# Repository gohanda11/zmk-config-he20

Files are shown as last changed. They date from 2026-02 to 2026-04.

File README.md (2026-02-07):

# HE20 - Hall Effect キーボード

XIAO nRF52840 + SN74LV4051A x3 + GH39FKSW による Hall Effect キーボードの ZMK ファームウェア設定。

## ハードウェア構成

| 要素 | 仕様 |
|---|---|
| MCU | Seeed XIAO nRF52840 |
| Hall Effect スイッチ | GH39FKSW |
| アナログマルチプレクサ | SN74LV4051A x 3 |
| トラックボールセンサー | PMW3610 ([zmk-pmw3610-driver](https://github.com/gohanda11/zmk-pmw3610-driver)) |
| ドライバ | [zmk-feature-hall-effect](https://github.com/gohanda11/zmk-feature-hall-effect) (フォーク版) |

## キーレイアウト

22 スイッチ位置を全て定義。未実装のキーは `&none` を割り当てる。

```
┌──────┬──────┬──────┬──────┬──────┐
│ HE1  │ HE2  │ HE3  │ HE4  │ HE5  │  Row 0
├──────┼──────┼──────┼──────┼──────┤
│ HE6  │ HE7  │ HE8  │ HE9  │ HE10 │  Row 1
├──────┼──────┼──────┼──────┼──────┤
│ HE11 │ HE12 │ HE13 │ HE14 │ HE15 │  Row 2
├──────┼──────┼──────┼──────┼──────┤
│ HE16 │ HE17 │ HE18 │ HE19 │ HE20 │  Row 3
└──────┴──────┴──────┴──────┴──────┘
┌─────────────┐      ┌─────────────┐
│  HE21 (2U)  │      │  HE22 (2U)  │  Row 4
└─────────────┘      └─────────────┘
```

Row 3 の 1U キーと Row 4 の 2U キーは物理的に入れ替えて使用できる。
取り付けていないキーには `&none` を設定する。

## トラックボール

PMW3610 センサーを J1 コネクタ経由で接続。

| 信号 | ピン | GPIO |
|---|---|---|
| CS | D0 | P0.02 |
| SDIO (MOSI/MISO) | D4 | P0.04 |
| SCLK | D5 | P0.05 |
| MOTION (IRQ) | D6 | P1.11 |

- automouse-layer: MOUSE (layer 1) - トラックボール操作時に自動切替
- scroll-layers: SCROLL (layer 5) - スクロールモード

## ビルド方法

GitHub Actions で自動ビルド。push すると `.github/workflows/build.yml` が実行される。

## ファイル構成

```
zmk-config-he20/
├── .github/workflows/build.yml
├── build.yaml
├── zephyr/module.yml
├── config/
│   ├── west.yml              # ZMK + zmk-feature-hall-effect モジュール定義
│   ├── he20.keymap            # キーマップ (7レイヤー)
│   └── he20.json              # 物理レイアウト定義 (keymap-editor 用)
└── boards/shields/he20/
    ├── Kconfig.shield
    ├── Kconfig.defconfig
    ├── he20.conf              # Kconfig 設定
    ├── he20.overlay           # Devicetree (kscan, レイアウト, transform)
    └── he20.zmk.yml           # シールドメタデータ
```

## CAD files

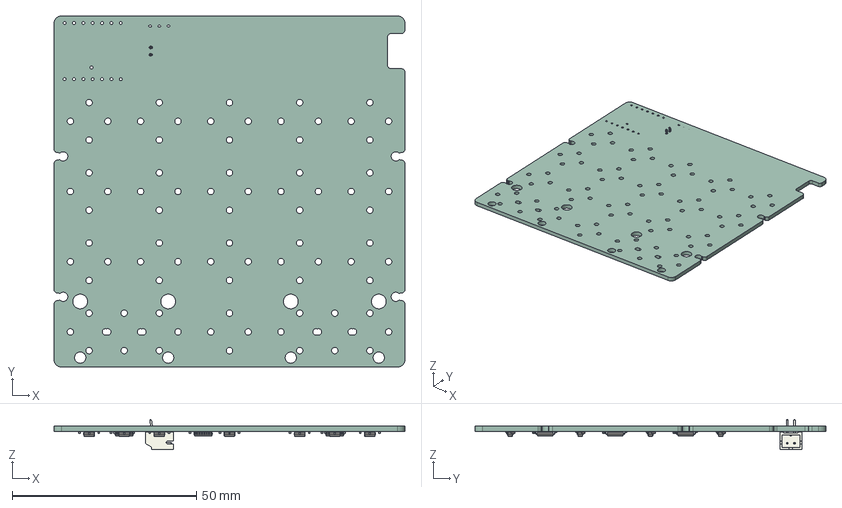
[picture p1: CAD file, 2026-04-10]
data/pcb.step
95.2 x 95.2 x 8.25 mm
SOT-23-3 x 22
C_0402_1005Metric x 47
TSSOP-16_4.4x5mm_P0.65mm x 3
JST_PH_S2B-PH-K_1x02_P2.00mm_Horizontal
xiao-test_PCB

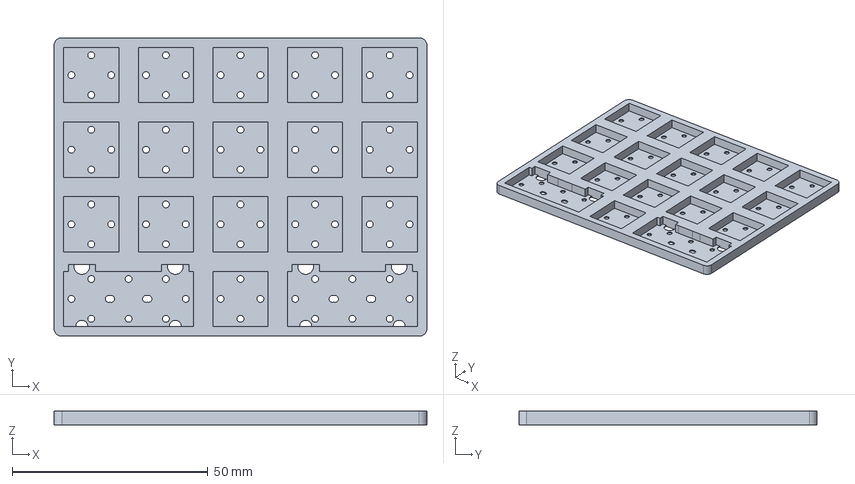
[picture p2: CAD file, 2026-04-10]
data/form.stp
95.2 x 76.2 x 3.50 mm

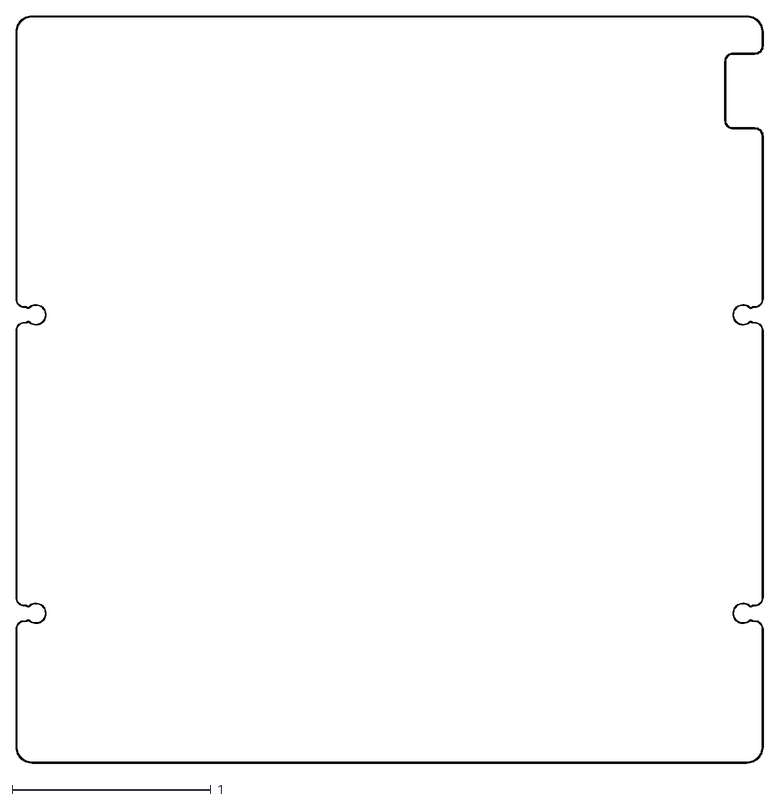
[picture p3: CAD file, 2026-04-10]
data/he20-Edge_Cuts.dxf
3.75 x 3.75

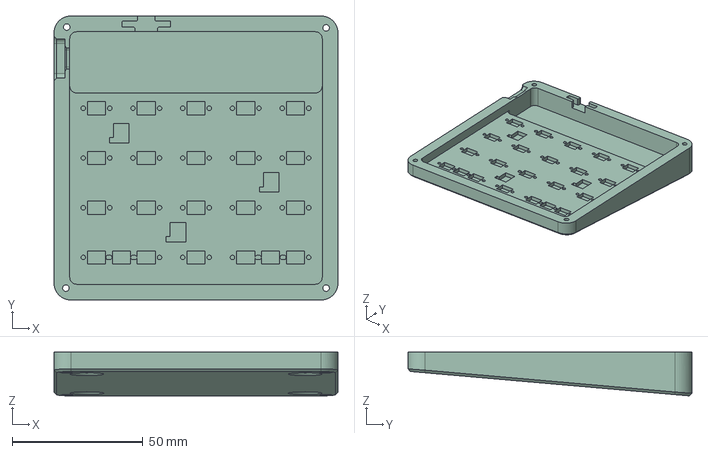
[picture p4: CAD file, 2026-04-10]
data/case_bottom.stp
108.8 x 108.8 x 16.8 mm

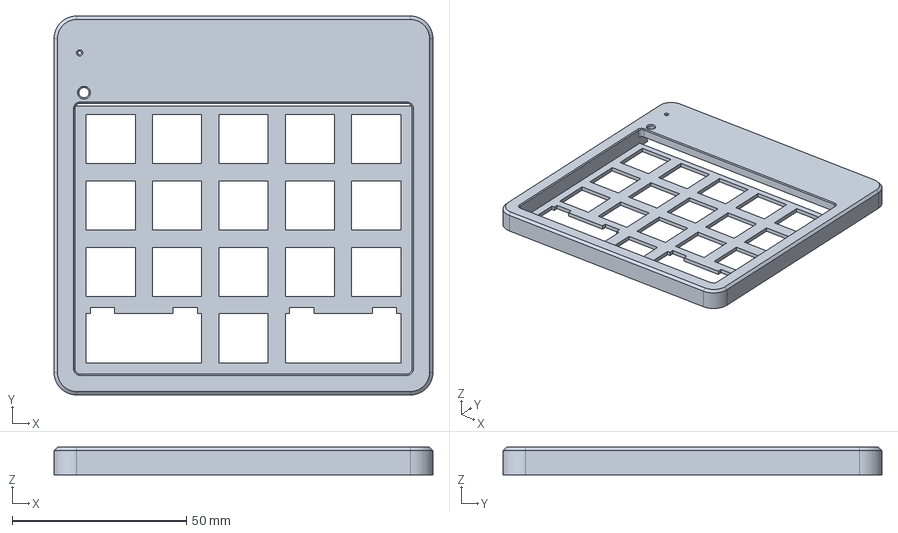
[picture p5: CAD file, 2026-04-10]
data/case_top.stp
108.8 x 108.8 x 8.00 mm

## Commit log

2026-02-07 fix: update board name for Zephyr 4.1.0 compatibility
    Rename seeeduino_xiao_ble to xiao_ble to match the new board naming
    convention in Zephyr 4.1.0.
2026-02-07 fix: move &he_pass node reference outside root block
    Node reference overrides (&label { }) must be at the top level of the
    devicetree file, not inside the / { } block.
2026-02-07 feat: switch to GH39FKSW sensor and default to 2U right layout
    - Change default physical layout from 1U to transform_2u_right (19 keys)
    - Update keymap to 19-key layout (Row 3: HE16, HE17, HE18, HE22)
    - Update sensor reference from MT9102ET to GH39FKSW
    - Update he20.zmk.yml requires to xiao_ble
    - Rewrite README with updated hardware info and layout docs
2026-02-07 refactor: use single 22-key layout showing all switch positions
    Replace the 4 layout variants with a single layout that shows all 22
    switch positions (HE1-HE22). Uninstalled keys use &none bindings.
    This ensures keymap-editor correctly displays 2U keys.
    Current config uses HE22 (2U right), with HE19/HE20/HE21 set to &none.
2026-02-07 fix: add row gap before HE21/HE22 2U keys in layout
    Move 2U keys from y=4 to y=5 (overlay: 400->500) to create a visual
    gap between Row 3 and the 2U keys, matching the physical PCB layout.
2026-02-07 feat: add PMW3610 trackball support
    Add PMW3610 trackball sensor via SPI0 on J1 connector
    (CS=D0/P0.02, SDIO=D4/P0.04, SCLK=D5/P0.05, IRQ=D6/P1.11).
    Configure automouse-layer=1 (MOUSE) and scroll-layers=5 (SCROLL),
    with mouse buttons (MB1/MB3/MB2) on MOUSE layer Row 3.
2026-02-07 fix: switch to badjeff/zmk-pmw3610-driver for Zephyr 4.1 compatibility
    Replace gohanda11 driver (pixart,pmw3610) with badjeff driver
    (pixart,pmw3610-alt) to avoid DTS binding conflict with Zephyr 4.1's
    built-in pixart,pmw3610. Migrate automouse from driver-level config
    to ZMK input-processors (zip_temp_layer).
2026-02-12 Add stack size configurations for hall effect processing
    Hall effect driver requires larger stack sizes than default ZMK settings.
    Without these, firmware crashes at boot before BLE initialization,
    preventing the device from being recognized as HE20.
2026-02-12 Trigger rebuild after hall effect module fix
2026-02-12 Add explicit ADC channel definitions for hall effect sensors
    Configure ADC channels 1, 4, 5 with proper gain (1/2), internal
    reference, 10us acquisition time, and 12-bit resolution matching
    the partialgauss reference implementation.
2026-02-12 Switch ZMK to cr3eperall fork with child node dependencies fix
    Use cr3eperall/zmk@fix-child-node-dependencies instead of
    zmkfirmware/zmk@main, matching the partialgauss reference
    implementation that works with the hall effect module.
2026-02-12 Disable trackball/PMW3610 for debugging
    Comment out all trackball-related overlay nodes and conf settings
    to isolate whether the PMW3610 driver or hall effect driver is
    causing the boot crash.
2026-02-12 Fix zmk,kscan to use he_kscan directly instead of kscan_forwarder
    The kscan_forwarder uses a custom API (kscan_forwarder_api) that is
    incompatible with Zephyr's standard kscan_driver_api. When ZMK called
    kscan_config/kscan_enable on the forwarder, it caused API mismatch
    crashes (wrong function pointers called with wrong arguments).
    Changed zmk,kscan and physical layout kscan to reference &he_kscan
    directly, which implements the proper kscan_driver_api. Also disabled
    calibrate mode so the keyboard generates actual key events instead of
    just printing raw ADC values to serial.
2026-02-12 Fix key input: add calibration values and per-key state tracking
    - Add default-calibration-min/max (2000/3300) to match actual ADC range
    - Change he_pass param from 0 to 8 (columns per group) for per-key indexing
    - Update keymap-size from 22 to 24 (3 groups x 8 addresses)
2026-02-12 Fix key direction: add switch-pressed-is-higher to all groups
    Hall effect sensors output higher ADC values when keys are pressed.
    Without this flag, the height mapping is inverted - rest position maps
    to near-zero height, causing all keys to falsely trigger on boot and
    preventing normal key detection.
2026-02-12 Fix ADC saturation: change gain to 1/4 and correct calibration
    Based on analysis of chai45he reference firmware (identical circuit):
    - ADC GAIN_1_2 (max 1.2V) caused saturation since sensor rest voltage
    is ~1.37V. Changed to GAIN_1_4 (max 2.4V) to capture full range.
    - Removed incorrect switch-pressed-is-higher (ADC decreases when
    pressed, matching chai45he's invert_adc=true behavior).
    - Adjusted calibration values (min=1400, max=2400) for GAIN_1_4 range.
2026-02-12 fix: hall effect sensor configuration and missing Kconfigs
2026-02-12 fix: correct Hall Effect Kconfig symbol names
2026-02-12 fix: adjust ADC gain and remove incorrect inversion property
2026-02-12 fix: disable PM_DEVICE to allow ADC/GPIO initialization
2026-02-12 fix: disable battery reporting to avoid Anomaly 212 and enable calibration logs
2026-02-12 Optimize HE thresholds and disable calibration mode based on log analysis
2026-04-10 add: CAD files (STEP/DXF) to data folder
    [case_bottom.stp, case_top.stp, form.stp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]
